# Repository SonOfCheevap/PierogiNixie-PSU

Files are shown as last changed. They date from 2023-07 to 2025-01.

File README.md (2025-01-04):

# PierogiNixie-PSU
A simple 12v to 150v-250v DC-DC Power supply for use with nixie tubes.

This is a modified version of an already existing PSU. Link to the original: https://www.electronics-lab.com/project/hv-nixie-dc-dc-switching-power-supply/

## New with V1.2
- Adjustable output AND hardwired resistor options available (150V-250V with variable resistor, 170V with set resistor)
- Cleaner routing
- Power planes
- Updated schematic to be more readable
- Included schematic as PDF
- Smaller Footprint

# Features
- 12v barrel jack input and wire input
- Adjustable output range of 150V to 250V (Only on V1 and V1.2)
- Wire output
- Mounting for M3.5x6 Screw

# Pictures
V1.2 AS OF 1/3/2025

### Front
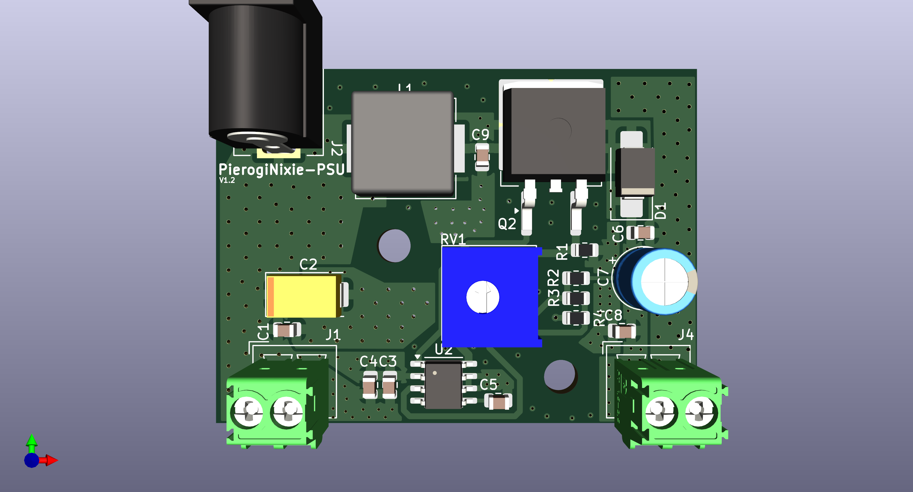
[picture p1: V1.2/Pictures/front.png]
front


### Back
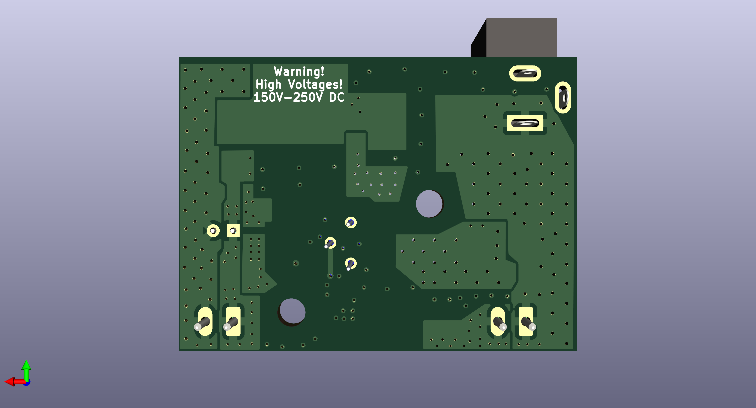
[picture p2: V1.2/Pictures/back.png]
back


### Render
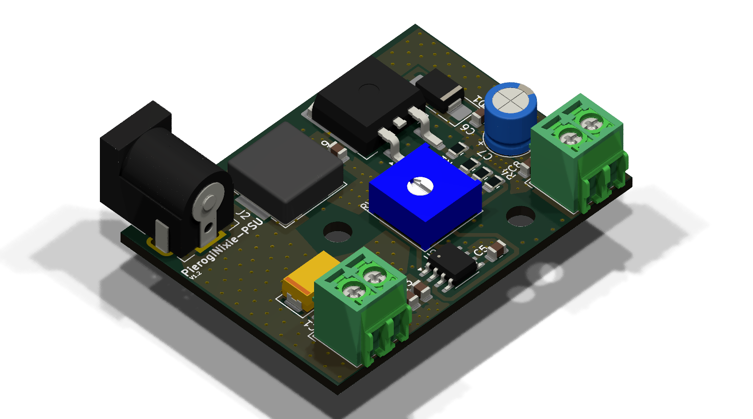
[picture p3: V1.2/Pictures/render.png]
render


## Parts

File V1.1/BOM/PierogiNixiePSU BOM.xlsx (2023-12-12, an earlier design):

Part ID | Part Description | Item Link | Cost Per | # Needed | Total
J1, J2 | OSTVN02A150 | https://www.digikey.com/en/products/detail/on-shore-technology-inc/OSTVN02A150/1588862 | $0.92 | 2 | $1.84
J3 | DC barrel jack | https://www.digikey.com/en/products/detail/kycon-inc/KLDX-0202-A/9975992 | $0.76 | 1 | $0.76
U1 | MAX1771CSA+T | https://www.digikey.com/en/products/detail/analog-devices-inc-maxim-integrated/MAX1771CSA-T/1520601 | $6.10 | 1 | $6.10
Q1 | IRF740STRLPBF | https://www.digikey.com/en/products/detail/vishay-siliconix/IRF740STRLPBF/856617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 | $2.80 | 1 | $2.80
L1 | IHLP4040DZER101M11 | https://www.digikey.com/en/products/detail/vishay-dale/IHLP4040DZER101M11/1220712 | $1.52 | 1 | $1.52
D1 | ES2F-E3/52T | https://www.digikey.com/en/products/detail/vishay-general-semiconductor-diodes-division/ES2F-E3-52T/1091445 | $0.43 | 1 | $0.43
C1 | TAJD107K020RNJ | https://www.digikey.com/en/products/detail/kyocera-avx/TAJD107K020RNJ/563829 | $1.10 | 1 | $1.10
C2, C3 | C0805C104K3RAC7210 | https://www.digikey.com/en/products/detail/kemet/C0805C104K3RAC7210/16894137 | $0.12 | 2 | $0.24
C4 | UVZ2E4R7MPD | https://www.digikey.com/en/products/detail/nichicon/UVZ2E4R7MPD/589155 | $0.49 | 1 | $0.49
C5 | C2012X7T2E104M125AE | https://www.digikey.com/en/products/detail/tdk-corporation/C2012X7T2E104M125AE/2616394 | $0.30 | 1 | $0.30
R1 | RK73H2ATTD1504F | https://www.digikey.com/en/products/detail/koa-speer-electronics-inc/RK73H2ATTD1504F/10234155 | $0.10 | 1 | $0.10
R2 | KDV08FR050ET | https://www.digikey.com/en/products/detail/ohmite/KDV08FR050ET/10476566 | $0.30 | 1 | $0.30
R3 | RNCP0805FTD10K0TR | https://www.digikey.com/en/products/detail/stackpole-electronics-inc/RNCP0805FTD10K0/2240262 | $0.10 | 1 | $0.10
R4 | RK73H2ATTD3401F | https://www.digikey.com/en/products/detail/koa-speer-electronics-inc/RK73H2ATTD3401F/10234136 | $0.10 | 1 | $0.10
Board | PierogiNixie-PSU | N/A | $1.40 | 1 | $1.40
 |  |  |  | Final Total: | $17.58
 |  |  |  | DOES NOT INCLUDE SHIPPING AND TAX

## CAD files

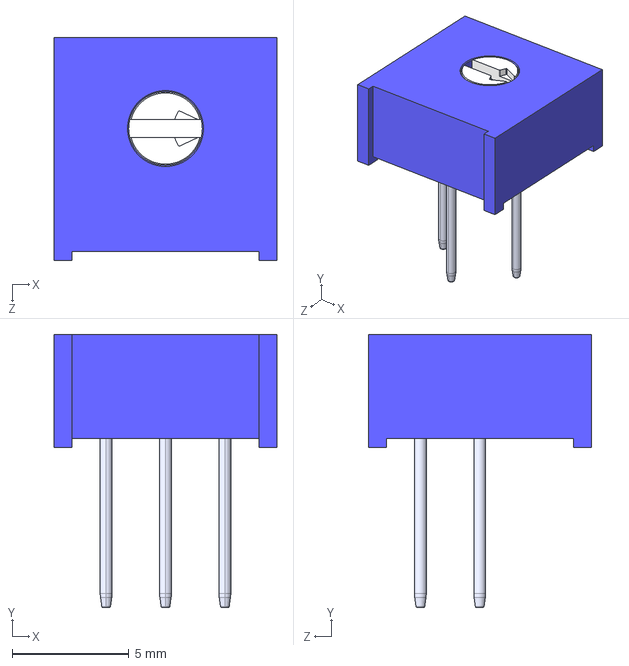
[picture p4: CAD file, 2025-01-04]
V1.2/3D/3386P-1-502LF.STEP
9.53 x 11.7 x 9.53 mm

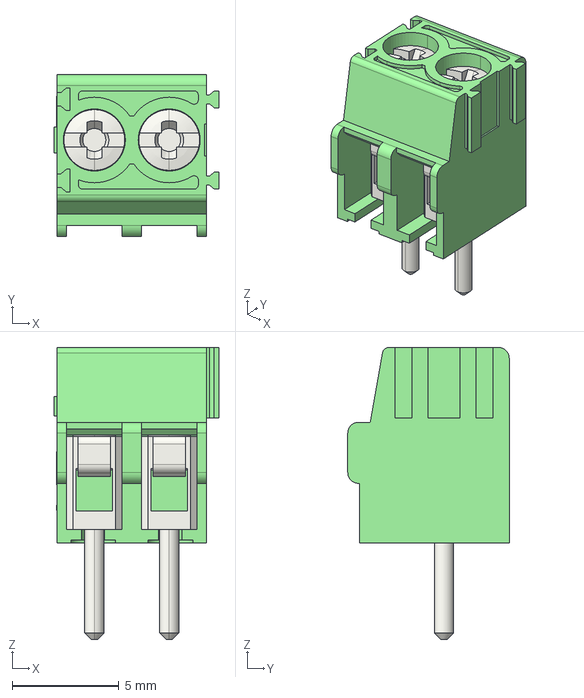
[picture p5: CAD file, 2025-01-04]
V1.2/3D/1984617.stp
7.70 x 7.55 x 13.6 mm

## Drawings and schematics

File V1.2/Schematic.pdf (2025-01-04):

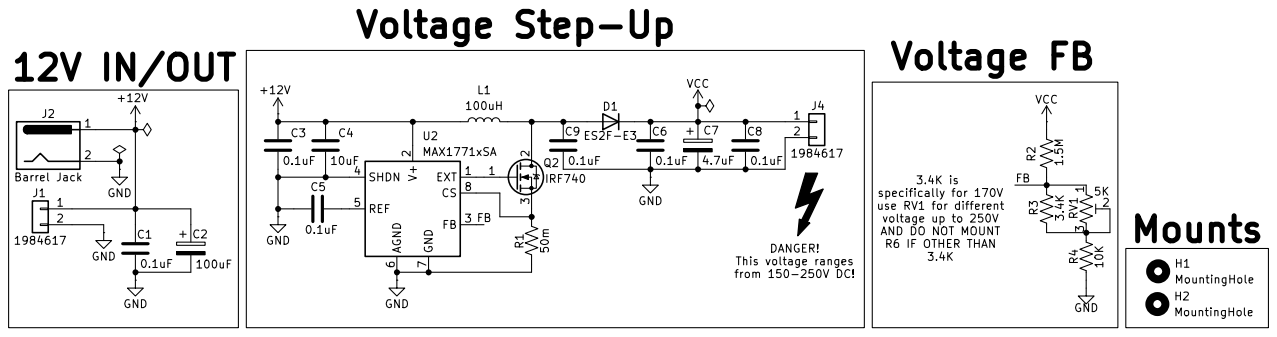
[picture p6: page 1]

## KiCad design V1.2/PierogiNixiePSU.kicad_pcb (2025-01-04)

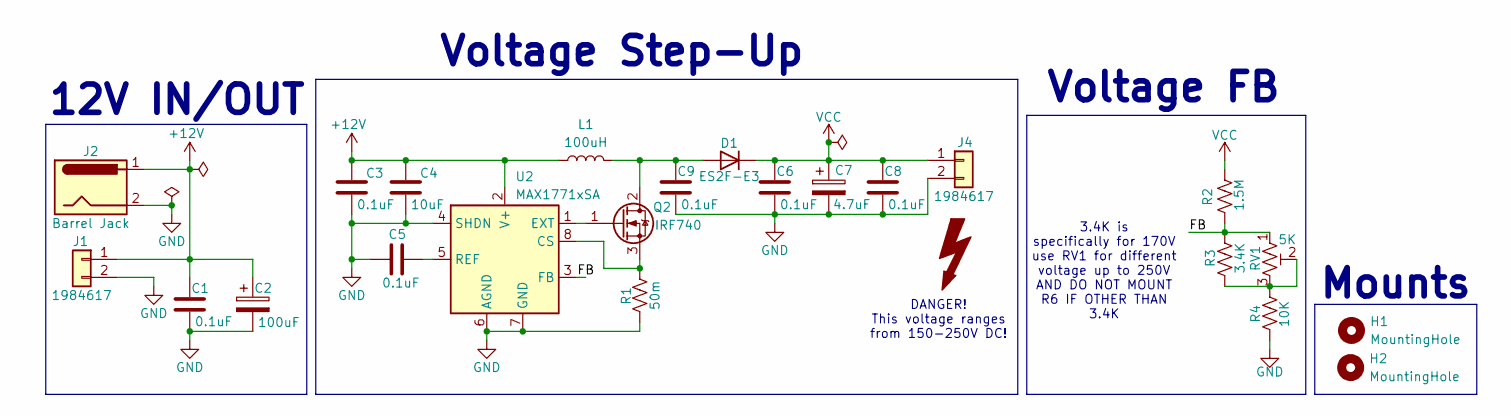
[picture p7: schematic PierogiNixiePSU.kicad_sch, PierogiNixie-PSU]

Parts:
C1, C3, C5, C6, C8, C9: 0.1uF; C_0805_2012Metric
C2: 100uF; CP_EIA-7343-30_AVX-N; Manufacturer_Part_Number TAJD107K020RNJ; Mouser Part Number 581-TAJD107K020R
C4: 10uF; C_0805_2012Metric
C7: 4.7uF; CP_Radial_D6.3mm_P2.50mm
D1: ES2F-E3; D_SMB_Handsoldering
H1, H2: MountingHole; MountingHole_3.5mm
J1, J4: 1984617; PhoenixContact_MCV_1,5_2-G-3.5_1x02_P3.50mm_Vertical
J2: Barrel Jack; BarrelJack_Kycon_KLDX-0202-xC_Horizontal
L1: 100uH; L_Vishay_IHLP-4040
Q2: IRF740; TO-263-2
R1: 50m; R_0805_2012Metric
R2: 1.5M; R_0805_2012Metric
R3: 3.4K; R_0805_2012Metric
R4: 10K; R_0805_2012Metric
RV1: 5K; Potentiometer_Bourns_3386P_Vertical
U2: MAX1771xSA; SO-8_3.9x4.9mm_P1.27mm

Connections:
+12V: C1.1, C2.1, C3.1, C4.1, J1.1, J2.1, L1.1, U2.2 (V+)
/FB: R2.1, R3.2, RV1.1, U2.3 (FB)
GND: C1.2, C2.2, C3.2, C4.2, C5.2, C6.2, C7.2, C8.2, C9.2, J1.2, J2.2, J4.2, R1.1, R4.2, U2.4 (SHDN), U2.6 (AGND), U2.7 (GND)
unnamed: C9.1, D1.2 (A), L1.2, Q2.2 (D)
unnamed: Q2.1 (G), U2.1 (EXT)
unnamed: Q2.3 (S), R1.2, U2.8 (CS)
unnamed: R3.1, R4.1, RV1.2, RV1.3
unnamed: C5.1, U2.5 (REF)
VCC: C6.1, C7.1, C8.1, D1.1 (K), J4.1, R2.2

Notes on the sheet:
Mounts
12V IN/OUT
Voltage FB
3.4K is specifically for 170V use RV1 for different voltage up to 250V AND DO NOT MOUNT R6 IF OTHER THAN 3.4K
Voltage Step-Up
DANGER! This voltage ranges from 150-250V DC!

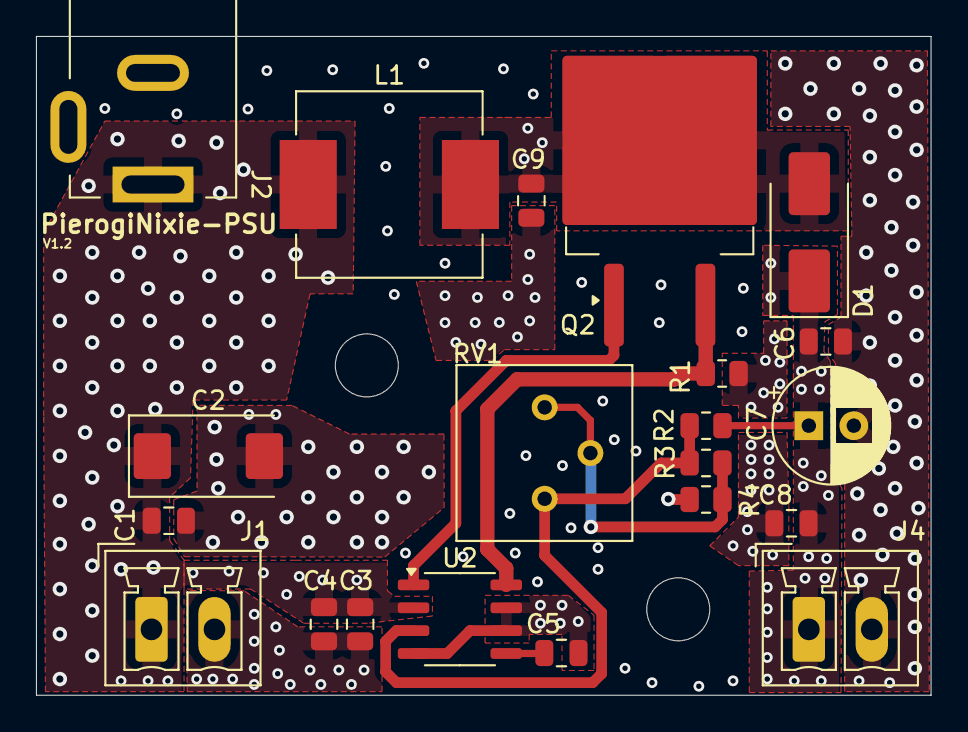
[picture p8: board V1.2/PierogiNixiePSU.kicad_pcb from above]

Board: 4 copper layers, 49.7 x 36.6 mm, 23 parts (0 on the bottom side), 9 nets.

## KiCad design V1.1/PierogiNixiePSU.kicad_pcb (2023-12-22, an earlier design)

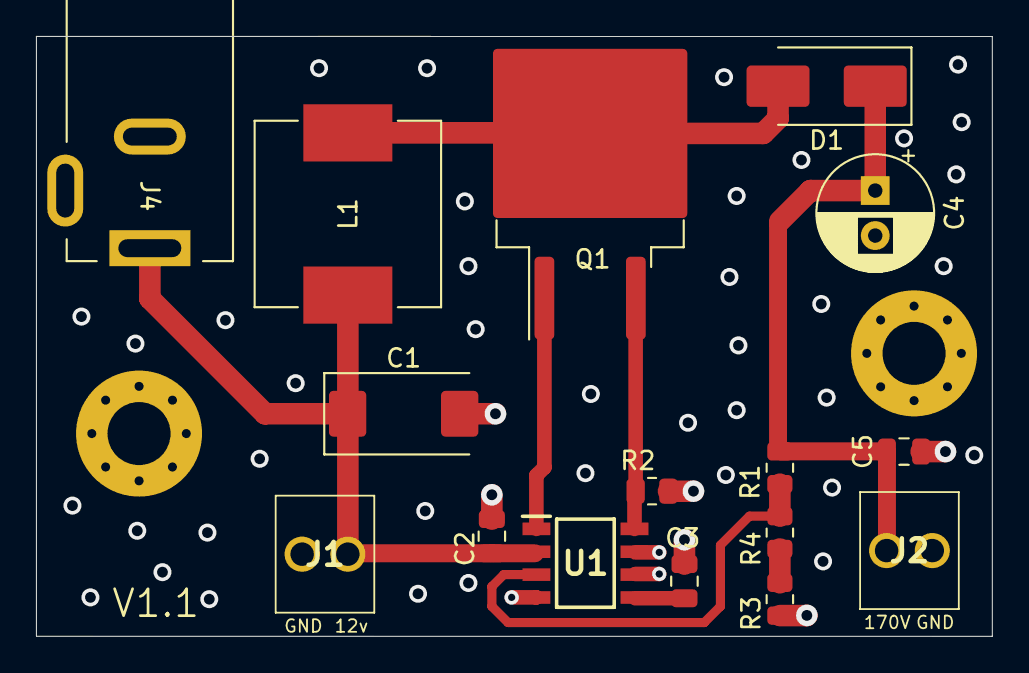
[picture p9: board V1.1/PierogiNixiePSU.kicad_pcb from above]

Board: 4 copper layers, 53.1 x 33.3 mm, 18 parts (0 on the bottom side), 9 nets.

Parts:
C1: 100uF; CP_EIA-7343-30_AVX-N
C2, C3: 100nF; C_0805_2012Metric
C4: 4.7uF; CP_Radial_D6.3mm_P2.50mm
C5: .1uF; C_0805_2012Metric
D1: ES2F-E3; D_SMB_Handsoldering
H1, H2: MountingHole; MountingHole_3.5mm_Pad_Via
J1, J2: OSTVN02A150
J4: Barrel_Jack; BarrelJack_Kycon_KLDX-0202-xC_Horizontal
L1: 100uH; L_Vishay_IHLP-4040
Q1: IRF740STRLPBF; TO-263-2
R1: 1.5M; R_0805_2012Metric
R2: 50m; R_0805_2012Metric
R3: 10k; R_0805_2012Metric
R4: 3.4K; R_0805_2012Metric
U1: MAX1771CSAT; SOIC127P600X175-8N

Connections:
/CS: Q1.3 (S), R2.2, U1.8 (CS)
/EXT: Q1.1 (G), U1.1 (EXT)
/FB: R1.1, R4.2, U1.3 (FB)
GND: C1.2, C2.2, C3.2, C4.2, C5.2, J1.1, J2.2, J4.2, R2.1, R3.2, U1.4 (SHDN), U1.6 (AGND), U1.7 (GND)
unnamed: D1.2 (A), L1.2, Q1.2 (D)
unnamed: C4.1, C5.1, D1.1 (K), J2.1, R1.2
unnamed: R3.1, R4.1
unnamed: C3.1, U1.5 (REF)
unnamed: C1.1, C2.1, J1.2, J4.1, L1.1, U1.2 (V+)

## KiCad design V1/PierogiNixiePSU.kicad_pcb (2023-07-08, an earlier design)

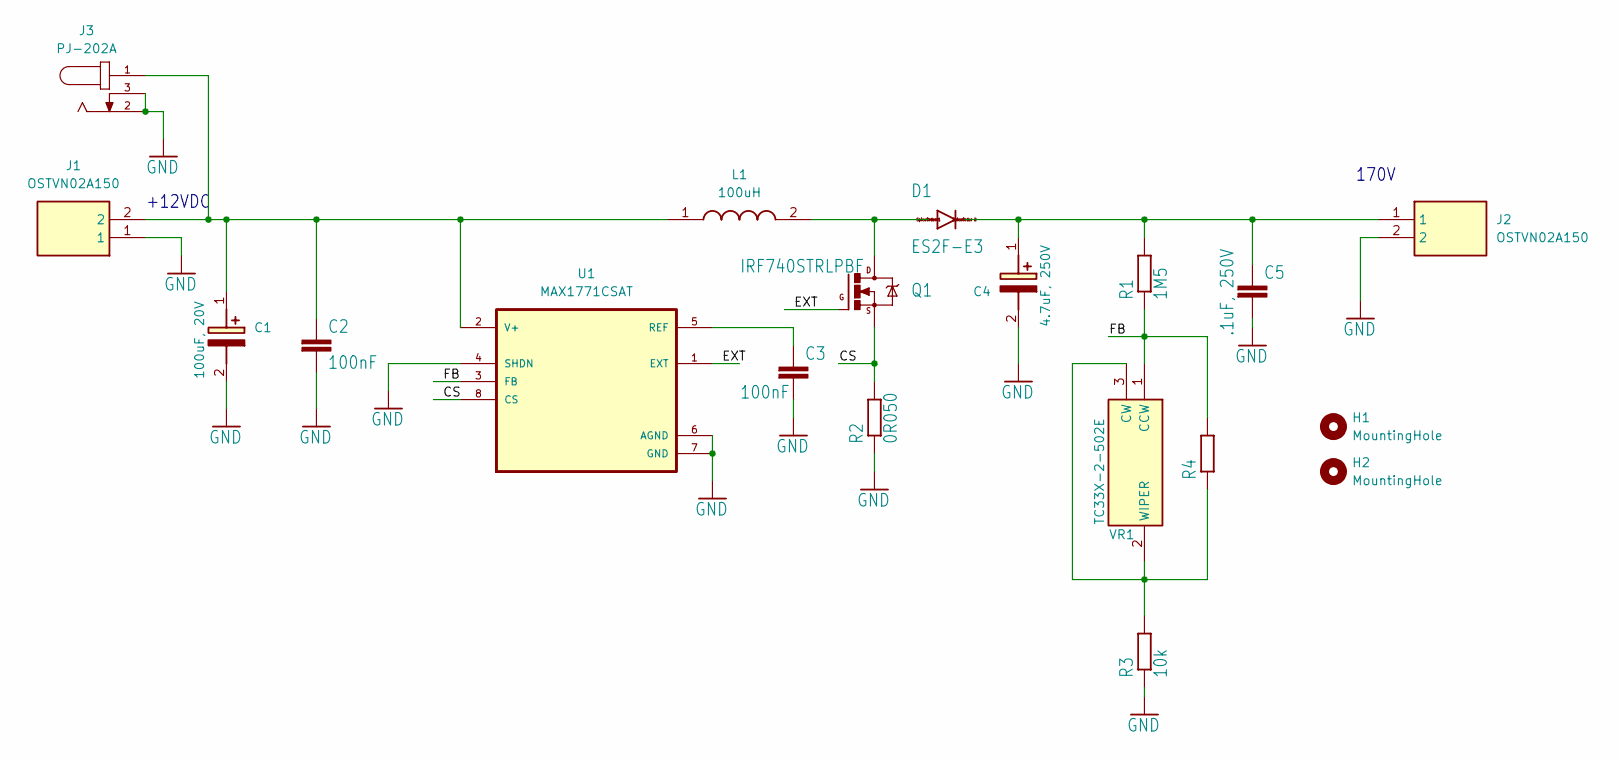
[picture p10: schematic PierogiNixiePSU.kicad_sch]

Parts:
C1: 100uF, 20V; CAPPM7344X310N; Manufacturer_Part_Number TAJD107K020RNJ; Mouser Part Number 581-TAJD107K020R
C2, C3: 100nF; C0805
C4: 4.7uF, 250V; CAPPRD250W50D655H1250; Manufacturer_Part_Number UVK2D0R1MED1TD
C5: .1uF, 250V; C0805
D1: ES2F-E3; SMB
H1, H2: MountingHole; MountingHole_3.5mm_Pad_Via
J1, J2: OSTVN02A150; Manufacturer_Part_Number OSTVN02A150
J3: PJ-202A; CUI_PJ-202A; PART_REV 1.02
L1: 100uH; INDPM108102X400N; Manufacturer_Part_Number IHLP4040DZER101M11; Mouser Part Number 70-IHLP4040DZER101M1
Q1: IRF740STRLPBF; TO-263_D2PAK
R1, R4: 1M5; R0805
R2: 0R050; R1206
R3: 10k; R0805
U1: MAX1771CSAT; SOIC127P600X175-8N
VR1: TC33X-2-502E; TC33X2503E; Manufacturer_Part_Number TC33X-2-502E; Mouser Part Number 652-TC33X-2-502E

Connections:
/CS: Q1.3 (S), R2.2, U1.8 (CS); also elsewhere on the board
/EXT: Q1.1 (G), U1.1 (EXT); also elsewhere on the board
/FB: R1.1, R4.2, U1.3 (FB), VR1.1 (CCW)
GND: C1.2 (-), C2.2, C3.2, C4.2 (-), C5.2, J1.1, J2.2, J3.2, J3.3, R2.1, R3.1, U1.4 (SHDN), U1.6 (AGND), U1.7 (GND)
unnamed: C1.1 (+), C2.1, J1.2, J3.1, L1.1, U1.2 (V+)
unnamed: C4.1 (+), C5.1, D1.C, J2.1, R1.2
unnamed 6: D1.A, L1.2, Q1.2 (D); also elsewhere on the board
unnamed: C3.1, U1.5 (REF)
unnamed: R3.2, R4.1, VR1.2 (WIPER), VR1.3 (CW)

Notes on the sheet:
+12VDC
170V

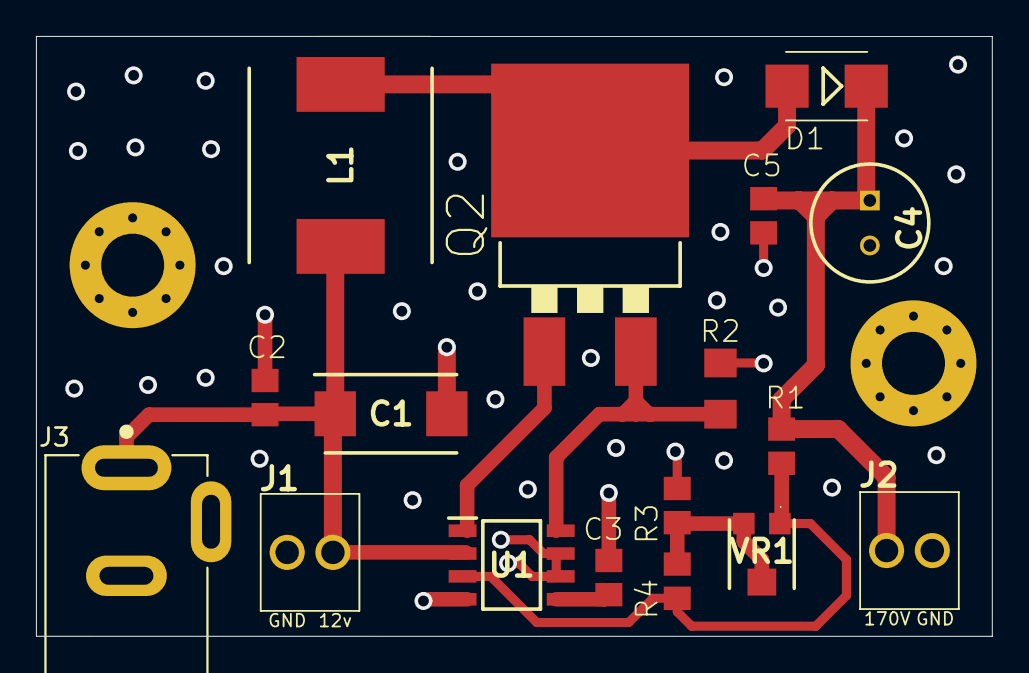
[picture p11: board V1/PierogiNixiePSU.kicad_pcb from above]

Board: 4 copper layers, 53.1 x 33.3 mm, 19 parts (0 on the bottom side), 9 nets.

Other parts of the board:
Q2: TO-263_D2PAK

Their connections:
/CS: Q2.3 (S); also elsewhere on the board
/EXT: Q2.1 (G); also elsewhere on the board
unnamed 6: Q2.2 (D); also elsewhere on the board

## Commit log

2023-07-07 Added DC barrel jack, updated BOM
    [PierogiNixiePSU BOM.xlsx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]
2023-07-07 Added mounting hole
    [PierogiNixiePSU-B_Cu.gbr, PierogiNixiePSU-B_Mask.gbr, PierogiNixiePSU-B_Paste.gbr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]
2023-07-08 Updated schematic and fixed thickness of GND traces
    [PierogiNixiePSU-B_Cu.gbr, PierogiNixiePSU-B_Mask.gbr, PierogiNixiePSU-B_Paste.gbr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]
2023-07-23 Updated BOM
    [PierogiNixiePSU BOM.xlsx]
2023-12-12 Created v1.1 of the board
    [PierogiNixiePSU BOM.xlsx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]
2023-12-12 dded Gerbers
    [PierogiNixiePSU BOM.xlsx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]
2023-12-22 Updated gnd vias
    [PierogiNixiePSU-B_Cu.gbl, PierogiNixiePSU-B_Mask.gbs, PierogiNixiePSU-B_Paste.gbp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]
2025-01-04 Created V1.2 of PSU
    [1984617.stp, 3386P-1-502LF.STEP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]
